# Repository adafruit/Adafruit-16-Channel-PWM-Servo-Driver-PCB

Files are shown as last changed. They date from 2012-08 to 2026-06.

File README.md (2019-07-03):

## Adafruit 16-Channel PWM Servo Driver PCB Eagle Files

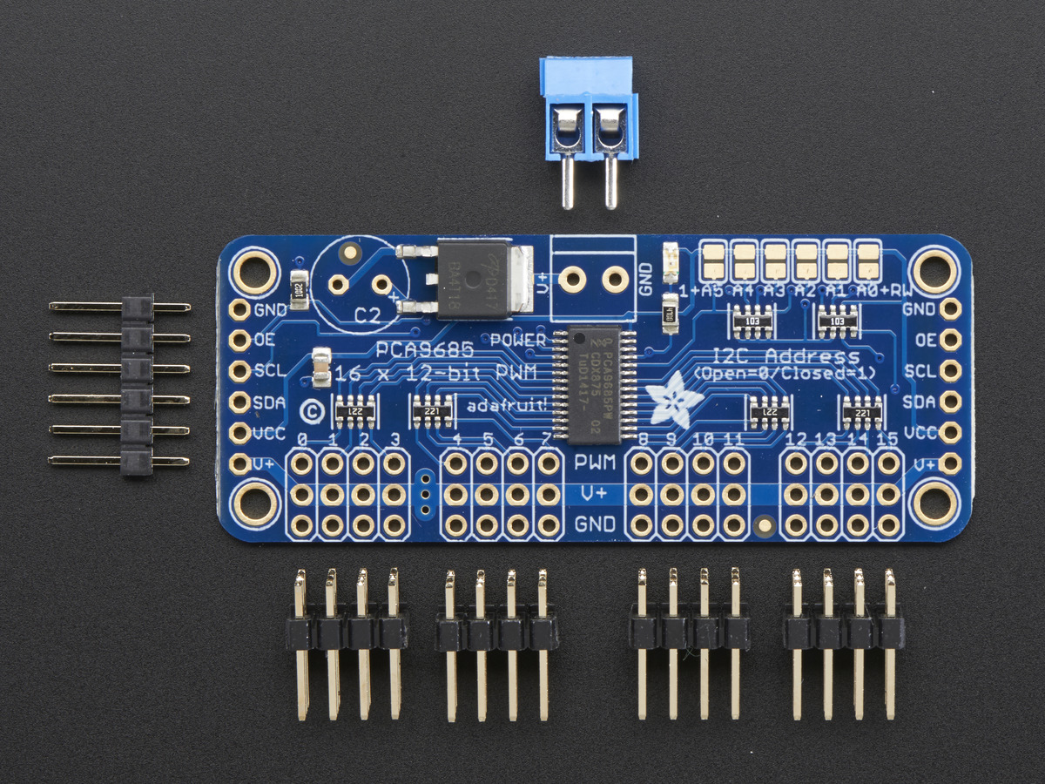
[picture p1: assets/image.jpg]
<a href="http://www.adafruit.com/products/815"><br/>
Click here to purchase one from the Adafruit shop</a>

This is the PCB for the Adafruit 16-channel PWM/Servo breakout board. Format is EagleCAD schematic and board layout
For more details, check out the product page at
* http://www.adafruit.com/products/815

### Description

You want to make a cool robot, maybe a hexapod walker, or maybe just a piece of art with a lot of moving parts. Or maybe you want to drive a lot of LEDs with precise PWM output. Then you realize that your microcontroller has a limited number of PWM outputs! What now? You could give up OR you could just get this handy PWM and Servo driver breakout.

When we saw this chip, we quickly realized what an excellent add-on this would be. Using only two pins, control 16 free-running PWM outputs! You can even chain up 62 breakouts to control up to 992 PWM outputs (which we would really like to see since it would be glorious)

* It's an i2c-controlled PWM driver with a built in clock. That means that, unlike the TLC5940 family, you do not need to continuously send it signal tying up your microcontroller, its completely free running!
* It is 5V compliant, which means you can control it from a 3.3V microcontroller and still safely drive up to 6V outputs (this is good for when you want to control white or blue LEDs with 3.4+ forward voltages)
* 6 address select pins so you can wire up to 62 of these on a single i2c bus, a total of 992 outputs - that's a lot of servos or LEDs
Adjustable frequency PWM up to about 1.6 KHz
* 12-bit resolution for each output - for servos, that means about 4us resolution at 60Hz update rate
* Configurable push-pull or open-drain output
* Output enable pin to quickly disable all the outputs

We wrapped up this lovely chip into a breakout board with a couple nice extras

* Terminal block for power input (or you can use the 0.1" breakouts on the side)
* Reverse polarity protection on the terminal block input. The terminal block included with your product may be blue or black.
* Green power-good LED
* 3 pin connectors in groups of 4 so you can plug in 16 servos at once (Servo plugs are slightly wider than 0.1" so you can only stack 4 next to each other on 0.1" header
* "Chain-able" design
* A spot to place a big capacitor on the V+ line (in case you need it)
* 220 ohm series resistors on all the output lines to protect them, and to make driving LEDs trivial
* Solder jumpers for the 6 address select pins

This product comes with a fully tested and assembled breakout as well as 4 pieces of 3x4 male straight header (for servo/LED plugs), a 2-pin terminal block (for power) and a piece of 6-pin 0.1" header (to plug into a breadboard). A little light soldering will be required to assemble and customize the board by attaching the desired headers but it is a 15 minute task that even a beginner can do.

### License

Adafruit invests time and resources providing this open source design, please support Adafruit and open-source hardware by purchasing products from [Adafruit](https://www.adafruit.com)!

Designed by Limor Fried/Ladyada for Adafruit Industries.

Creative Commons Attribution/Share-Alike, all text above must be included in any redistribution. See license.txt for additional details.

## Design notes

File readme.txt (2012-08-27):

This is the PCB for the Adafruit 16-channel PWM/Servo breakout board
Format is EagleCAD schematic and board layout

For more details, check out the product page at

-----> http://www.adafruit.com/products/815

Adafruit invests time and resources providing this open source design, 
please support Adafruit and open-source hardware by purchasing 
products from Adafruit!

Designed by Adafruit Industries.  
Creative Commons Attribution, Share-Alike license, check license.txt for more information
All text above must be included in any redistribution

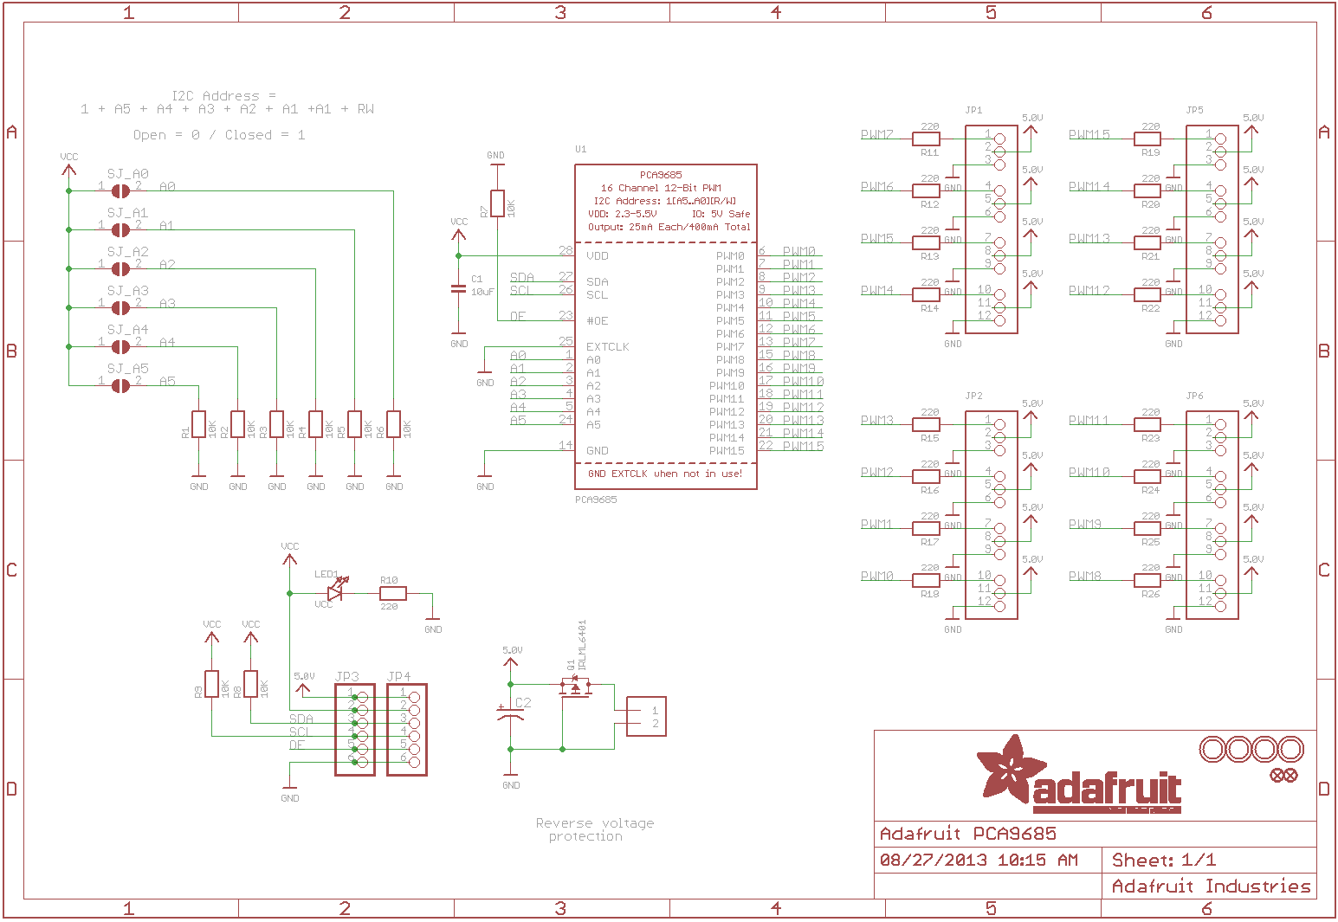
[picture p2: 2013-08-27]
Adafruit PCA9685.png

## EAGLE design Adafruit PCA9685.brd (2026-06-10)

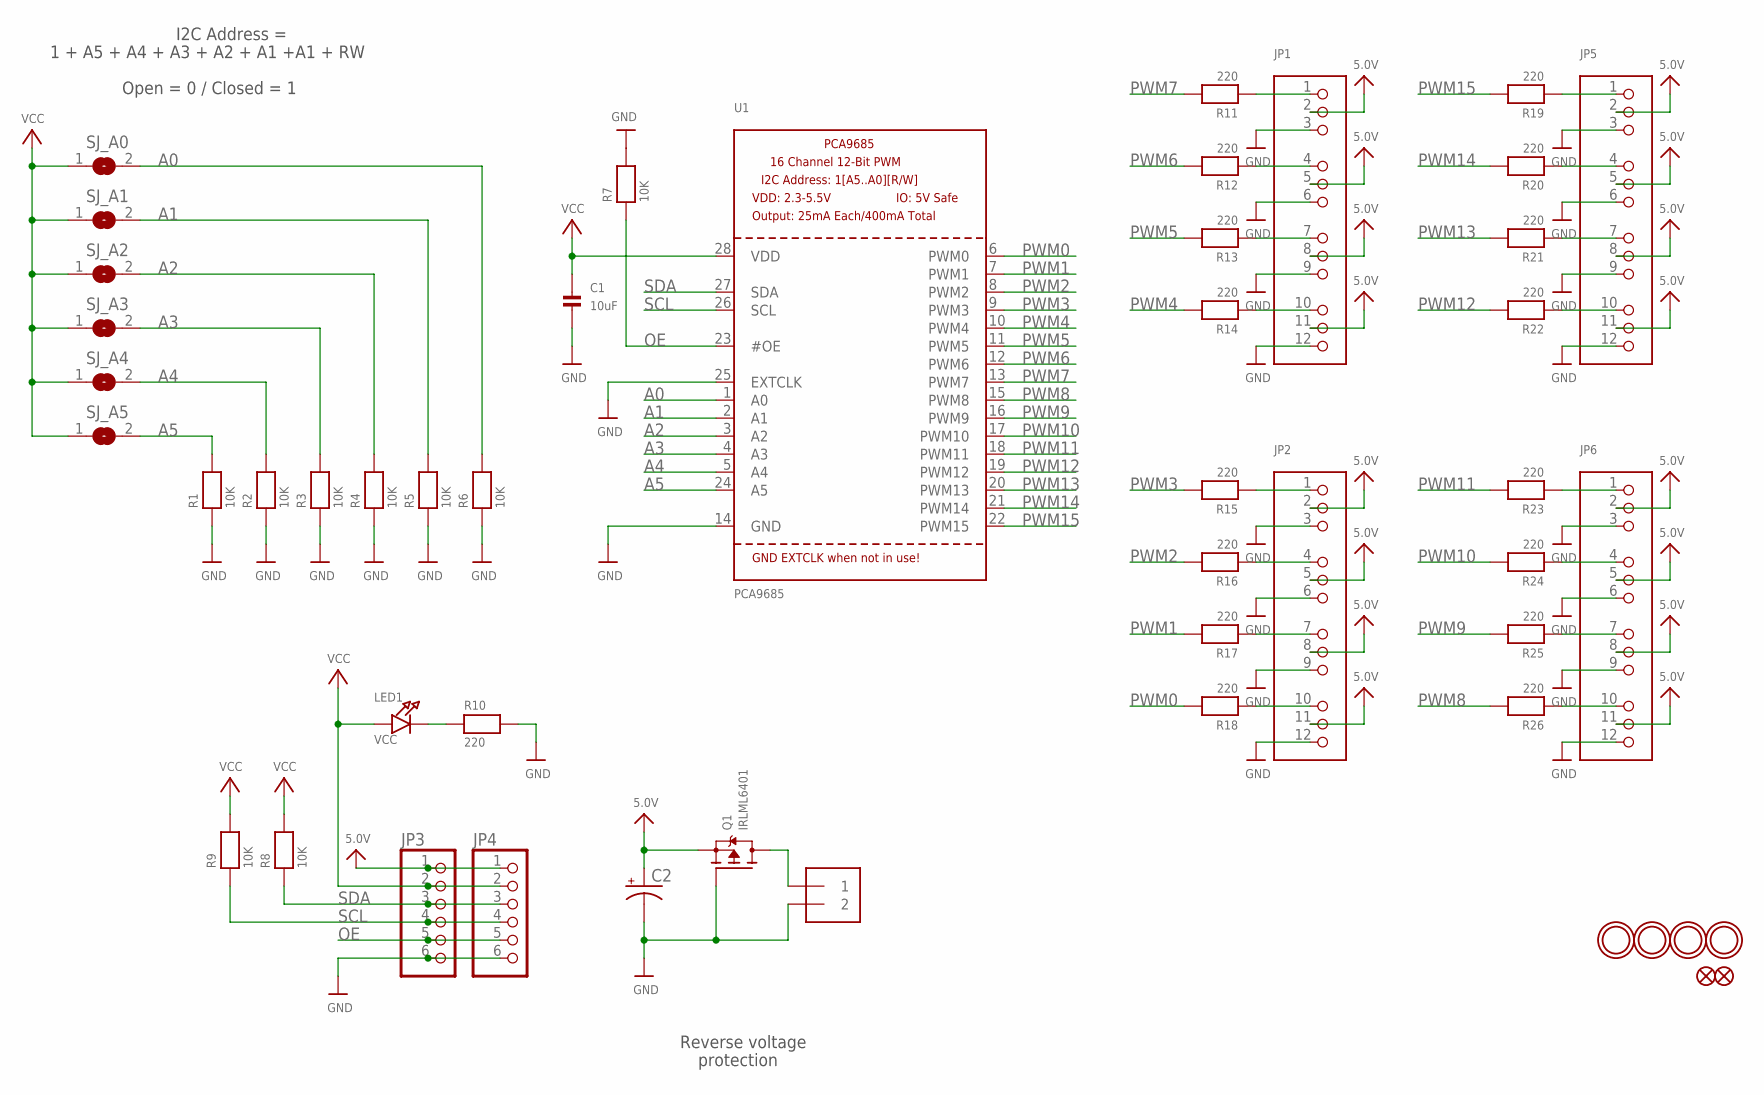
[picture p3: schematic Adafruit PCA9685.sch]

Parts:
C1: 10uF; 0805
C2: CPOL-USE3.5-8; E3,5-8
FID1, FID2: FIDUCIAL""; FIDUCIAL_1MM
J1: TERMBLOCK_1X2-3.5MM; 1X2-3.5MM
JP1, JP2, JP5, JP6: HEADER-3X04; 3X04
JP3, JP4: PINHD-1X6CB; 1X06-CLEANBIG
LED1: VCC; CHIPLED_0805
Q1: IRLML6401; SOT23-WIDE
R1, R2, R3, R4, R5, R6, R7, R8, R9: 10K; 0805
R10, R11, R12, R13, R14, R15, R16, R17, R18, R19, R20, R21, R22, R23, R24, R25, R26: 220; 0805
SJ_A0, SJ_A1, SJ_A2, SJ_A3, SJ_A4, SJ_A5: SOLDERJUMPERREFLOW_NOPASTE; SOLDERJUMPER_REFLOW_NOPASTE
U1: PCA9685; TSSOP28
U$47, U$48, U$49, U$50: MOUNTINGHOLE2.5; MOUNTINGHOLE_2.5_PLATED

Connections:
5.0V: C2.+, JP1.2, JP1.5, JP1.8, JP1.11, JP2.2, JP2.5, JP2.8, JP2.11, JP3.1, JP4.1, JP5.2, JP5.5, JP5.8, JP5.11, JP6.2, JP6.5, JP6.8, JP6.11, Q1.2 (S)
A0: R6.2, SJ_A0.2, U1.1 (A0)
A1: R5.2, SJ_A1.2, U1.2 (A1)
A2: R4.2, SJ_A2.2, U1.3 (A2)
A3: R3.2, SJ_A3.2, U1.4 (A3)
A4: R2.2, SJ_A4.2, U1.5 (A4)
A5: R1.2, SJ_A5.2, U1.24 (A5)
GND: C1.2, C2.-, J1.2, JP1.3, JP1.6, JP1.9, JP1.12, JP2.3, JP2.6, JP2.9, JP2.12, JP3.6, JP4.6, JP5.3, JP5.6, JP5.9, JP5.12, JP6.3, JP6.6, JP6.9, JP6.12, Q1.1 (G), R1.1, R2.1, R3.1, R4.1, R5.1, R6.1, R7.2, R10.2, U1.14 (GND), U1.25 (EXTCLK)
unnamed: LED1.C, R10.1
unnamed: JP1.4, R12.1
unnamed: JP1.1, R11.1
unnamed: JP1.7, R13.1
unnamed: JP1.10, R14.1
unnamed: JP2.1, R15.1
unnamed: JP2.4, R16.1
unnamed: JP2.7, R17.1
unnamed: JP2.10, R18.1
unnamed: JP6.10, R26.1
unnamed: JP6.7, R25.1
unnamed: JP6.4, R24.1
unnamed: JP6.1, R23.1
unnamed: JP5.10, R22.1
unnamed: JP5.7, R21.1
unnamed: JP5.4, R20.1
unnamed: JP5.1, R19.1
OE: JP3.5, JP4.5, R7.1, U1.23 (#OE)
PWM0: R18.2, U1.6 (PWM0)
PWM1: R17.2, U1.7 (PWM1)
PWM2: R16.2, U1.8 (PWM2)
PWM3: R15.2, U1.9 (PWM3)
PWM4: R14.2, U1.10 (PWM4)
PWM5: R13.2, U1.11 (PWM5)
PWM6: R12.2, U1.12 (PWM6)
PWM7: R11.2, U1.13 (PWM7)
PWM8: R26.2, U1.15 (PWM8)
PWM9: R25.2, U1.16 (PWM9)
PWM10: R24.2, U1.17 (PWM10)
PWM11: R23.2, U1.18 (PWM11)
PWM12: R22.2, U1.19 (PWM12)
PWM13: R21.2, U1.20 (PWM13)
PWM14: R20.2, U1.21 (PWM14)
PWM15: R19.2, U1.22 (PWM15)
PWRIN: J1.1, Q1.3 (D)
SCL: JP3.4, JP4.4, R9.1, U1.26 (SCL)
SDA: JP3.3, JP4.3, R8.1, U1.27 (SDA)
VCC: C1.1, JP3.2, JP4.2, LED1.A, R8.2, R9.2, SJ_A0.1, SJ_A1.1, SJ_A2.1, SJ_A3.1, SJ_A4.1, SJ_A5.1, U1.28 (VDD)

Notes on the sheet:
Reverse voltage
protection
1 + A5 + A4 + A3 + A2 + A1 +A1 + RW
I2C Address =
Open = 0 / Closed = 1

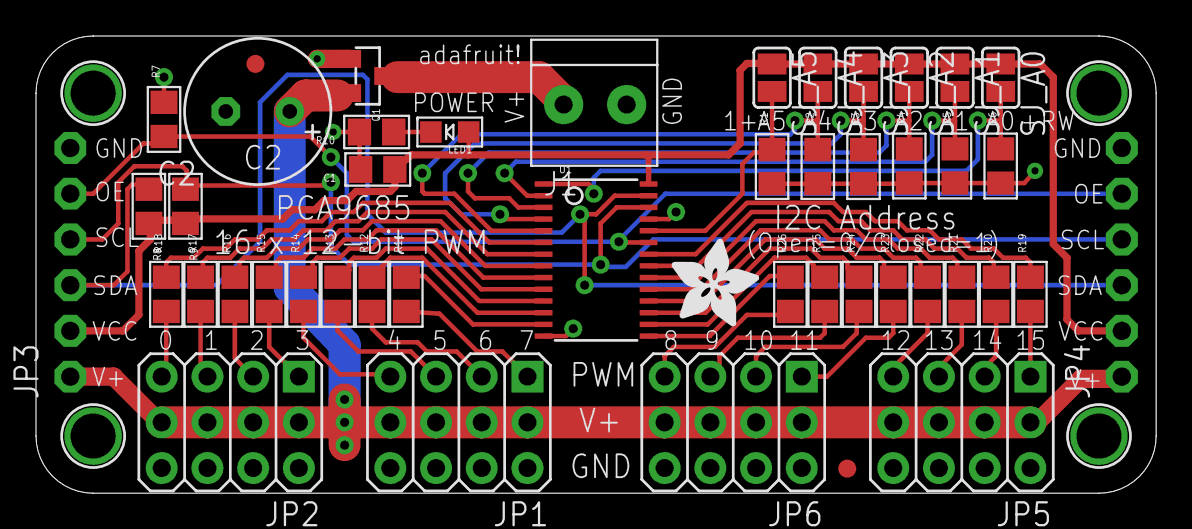
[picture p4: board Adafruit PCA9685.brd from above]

Board: 2 copper layers, 62.2 x 25.4 mm, 51 parts (0 on the bottom side), 46 nets.

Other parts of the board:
U$51: ADAFRUIT_5MM

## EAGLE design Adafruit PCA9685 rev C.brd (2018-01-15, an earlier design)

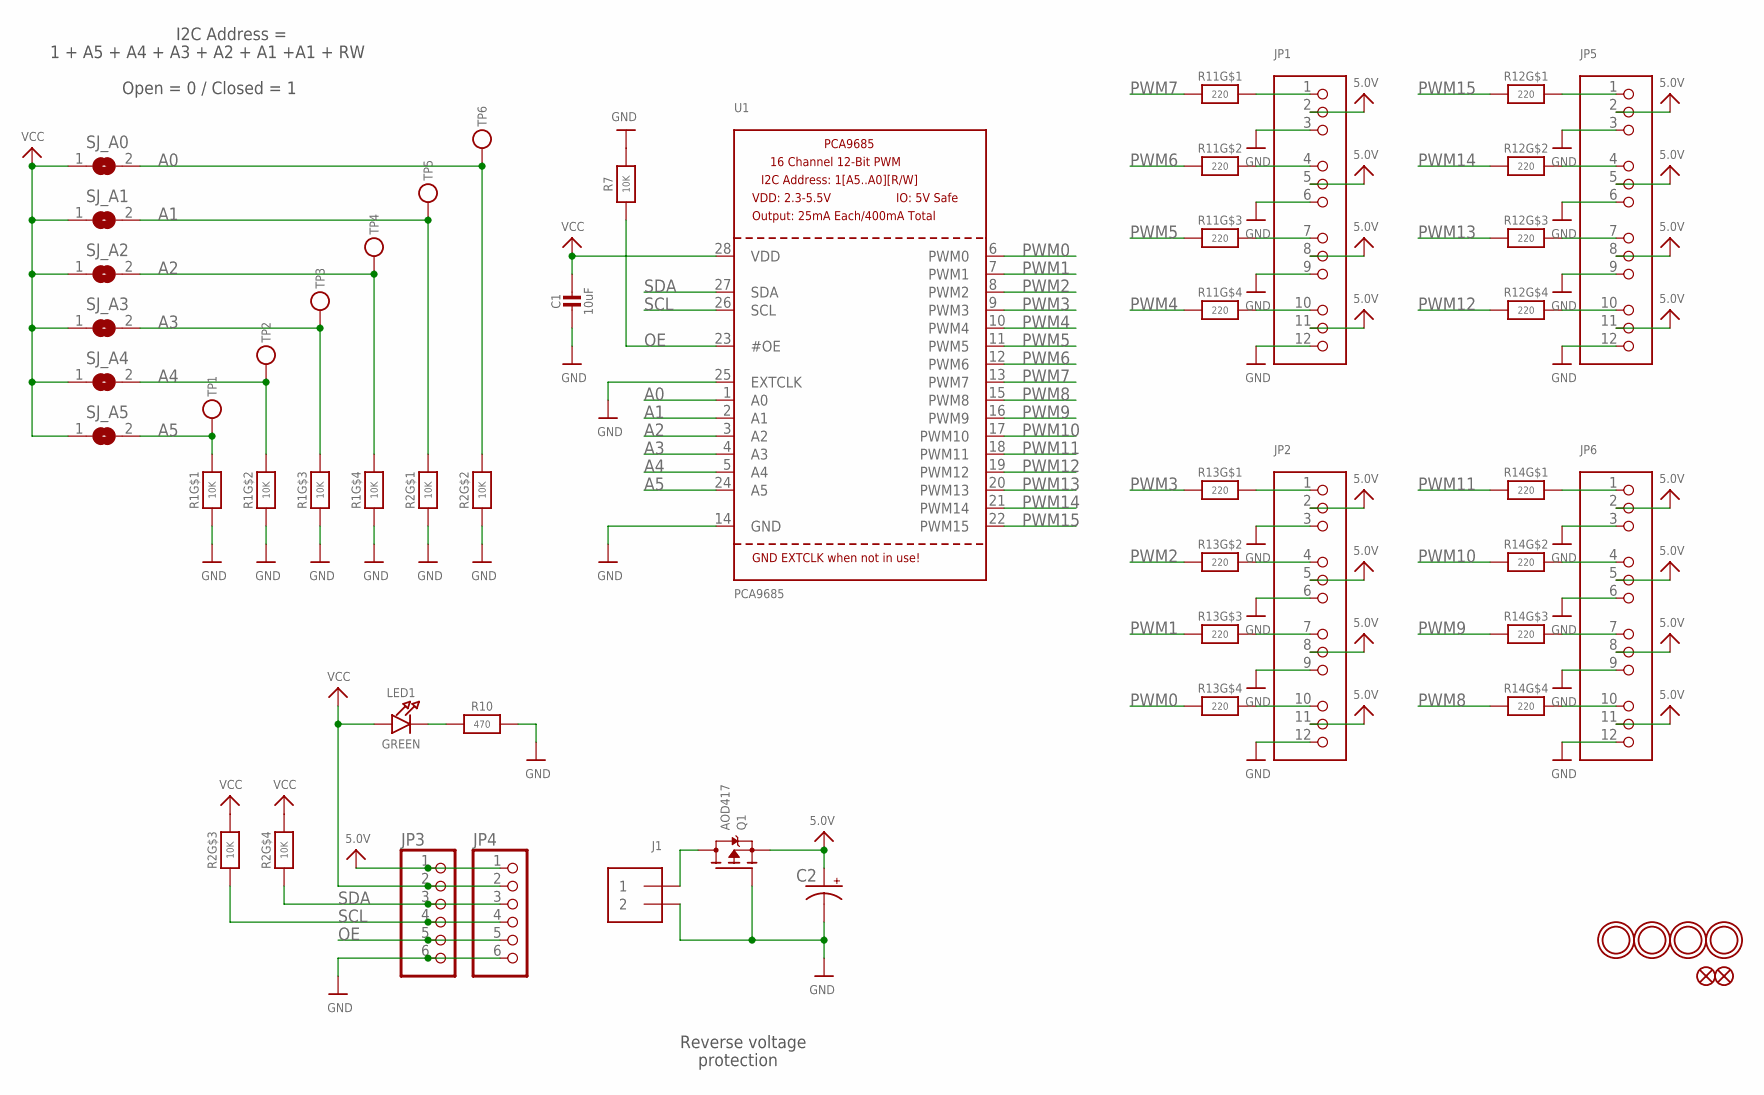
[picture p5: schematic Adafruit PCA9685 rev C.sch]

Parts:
C1: 10uF; 0805-NO
C2: CPOL-USE3.5-8; E3,5-8
FID1, FID2: FIDUCIAL""; FIDUCIAL_1MM
J1: TERMBLOCK_1X2; TERMBLOCK_1X2-3.5MM
JP1, JP2, JP5, JP6: HEADER-3X04; 3X04
JP3, JP4: PINHD-1X6CB; 1X06-CLEANBIG
LED1: GREEN; CHIPLED_0805_NOOUTLINE
Q1: AOD417; TO252
R1, R2: 10K; RESPACK_4X0603
R7: 10K; 0805-NO
R10: 470; _0805MP
R11, R12, R13, R14: 220; RESPACK_4X0603
SJ_A0, SJ_A1, SJ_A2, SJ_A3, SJ_A4, SJ_A5: SOLDERJUMPERREFLOW_NOPASTE; SOLDERJUMPER_REFLOW_NOPASTE
TP1, TP2, TP3, TP4, TP5, TP6: TESTPOINTROUND1MM; TESTPOINT_ROUND_1MM
U1: PCA9685; TSSOP28
U$47, U$48, U$49, U$50: MOUNTINGHOLE2.5; MOUNTINGHOLE_2.5_PLATED

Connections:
5.0V: C2.+, JP1.2, JP1.5, JP1.8, JP1.11, JP2.2, JP2.5, JP2.8, JP2.11, JP3.1, JP4.1, JP5.2, JP5.5, JP5.8, JP5.11, JP6.2, JP6.5, JP6.8, JP6.11, Q1.2 (S)
A0: R2.7 (2), SJ_A0.2, TP6.P$1, U1.1 (A0)
A1: R2.8 (2), SJ_A1.2, TP5.P$1, U1.2 (A1)
A2: R1.5 (2), SJ_A2.2, TP4.P$1, U1.3 (A2)
A3: R1.6 (2), SJ_A3.2, TP3.P$1, U1.4 (A3)
A4: R1.7 (2), SJ_A4.2, TP2.P$1, U1.5 (A4)
A5: R1.8 (2), SJ_A5.2, TP1.P$1, U1.24 (A5)
GND: C1.2, C2.-, J1.2, JP1.3, JP1.6, JP1.9, JP1.12, JP2.3, JP2.6, JP2.9, JP2.12, JP3.6, JP4.6, JP5.3, JP5.6, JP5.9, JP5.12, JP6.3, JP6.6, JP6.9, JP6.12, Q1.1 (G), R1.1, R1.2 (1), R1.3 (1), R1.4 (1), R2.1, R2.2 (1), R7.2, R10.2, U1.14 (GND), U1.25 (EXTCLK)
unnamed: LED1.C, R10.1
unnamed: JP1.4, R11.7 (2)
unnamed: JP1.1, R11.8 (2)
unnamed: JP1.7, R11.6 (2)
unnamed: JP1.10, R11.5 (2)
unnamed: JP2.1, R13.8 (2)
unnamed: JP2.4, R13.7 (2)
unnamed: JP2.7, R13.6 (2)
unnamed: JP2.10, R13.5 (2)
unnamed: JP6.10, R14.5 (2)
unnamed: JP6.7, R14.6 (2)
unnamed: JP6.4, R14.7 (2)
unnamed: JP6.1, R14.8 (2)
unnamed: JP5.10, R12.5 (2)
unnamed: JP5.7, R12.6 (2)
unnamed: JP5.4, R12.7 (2)
unnamed: JP5.1, R12.8 (2)
OE: JP3.5, JP4.5, R7.1, U1.23 (#OE)
PWM0: R13.4 (1), U1.6 (PWM0)
PWM1: R13.3 (1), U1.7 (PWM1)
PWM2: R13.2 (1), U1.8 (PWM2)
PWM3: R13.1, U1.9 (PWM3)
PWM4: R11.4 (1), U1.10 (PWM4)
PWM5: R11.3 (1), U1.11 (PWM5)
PWM6: R11.2 (1), U1.12 (PWM6)
PWM7: R11.1, U1.13 (PWM7)
PWM8: R14.4 (1), U1.15 (PWM8)
PWM9: R14.3 (1), U1.16 (PWM9)
PWM10: R14.2 (1), U1.17 (PWM10)
PWM11: R14.1, U1.18 (PWM11)
PWM12: R12.4 (1), U1.19 (PWM12)
PWM13: R12.3 (1), U1.20 (PWM13)
PWM14: R12.2 (1), U1.21 (PWM14)
PWM15: R12.1, U1.22 (PWM15)
PWRIN: J1.1, Q1.3 (D)
SCL: JP3.4, JP4.4, R2.3 (1), U1.26 (SCL)
SDA: JP3.3, JP4.3, R2.4 (1), U1.27 (SDA)
VCC: C1.1, JP3.2, JP4.2, LED1.A, R2.5 (2), R2.6 (2), SJ_A0.1, SJ_A1.1, SJ_A2.1, SJ_A3.1, SJ_A4.1, SJ_A5.1, U1.28 (VDD)

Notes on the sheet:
Reverse voltage
protection
1 + A5 + A4 + A3 + A2 + A1 +A1 + RW
I2C Address =
Open = 0 / Closed = 1

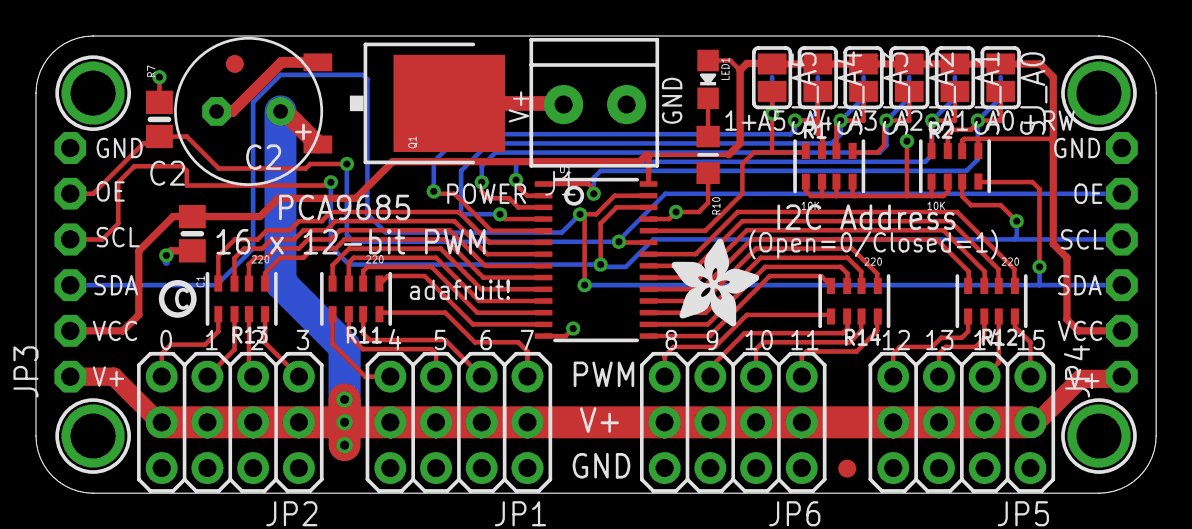
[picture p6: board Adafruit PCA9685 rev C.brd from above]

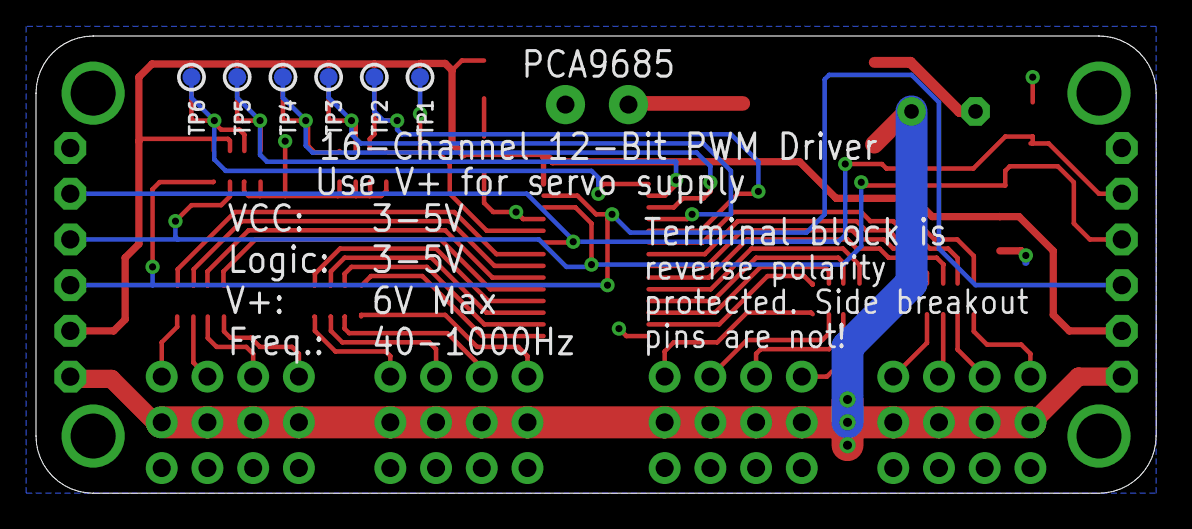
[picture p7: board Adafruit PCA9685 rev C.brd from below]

Board: 2 copper layers, 62.2 x 25.4 mm, 40 parts (6 on the bottom side), 46 nets.

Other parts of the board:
U$51: ADAFRUIT_5MM
U$54: PCBFEAT-REV-040

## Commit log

2013-08-27 Added a .png version of schematic
2026-06-03 update file format to XML
    [Adafruit PCA9685.brd, Adafruit PCA9685.sch]
